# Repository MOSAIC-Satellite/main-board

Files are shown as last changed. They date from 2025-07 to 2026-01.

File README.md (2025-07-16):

# Main Board

This is the repository for MOSAIC's Main Board.

For detailed information on the Main Board, check out its core documentation [here](https://www.mosaicsat.org/core_documentation/hardware/main_board/).

To get your own MOSAIC Main Board, visit the MOSAIC fabrication guide [here](https://www.mosaicsat.org/getting_mosaic/).

## Current Features

*Newest board version: 1.0*

| **Feature** |
| :----------- |
| Swappable Processor Slot |
| 2x Expandable Memory Slots |
| 2x Function Board Slots |
| USB/Battery Voltage Regulator |
| Qwiic Voltage Regulator |
| Built-in Resettable PTC Fuse |
| 2-Pin JST Connector |
| Single Cell LiPo Charge Circuit |
| USB Type C Connector |
| 2x Qwiic Connectors |
| SWD 2x5 Header |
| Multiplexer for UART1  |
| Boot and Reset Buttons |
| 3x I/O switches |

## Planned Changes

The following are the current plans for changes to MOSAIC's Main Board. 

- Remove one of the expandable memory slots and replace it with a permanent SD card slot. This means that those interested only in SD cards for memory storage don't need a separate PCB to add to the board. 

## Change Log

You can find the change log for the Main Board on MOSAIC's website [here](https://www.mosaicsat.org/core_documentation/hardware/main_board/change_log/).

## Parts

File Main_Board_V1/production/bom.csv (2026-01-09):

Designator | Footprint | Quantity | Value | LCSC Part #
C1, C4, C5 | 0603 | 3 | 4.7uF | C1705
C2, C7 | 0805 | 2 | 10uF | C318695
C3 | 0805 | 1 | 0.1uF | C20617880
C6, C8 | 0603 | 2 | 1.0uF | C1592
D1, D2, D3 | LED-0603 | 3 | LED RED CLEAR SMD | C125099
D4 | SMA-DIODE | 1 | DIODE SCHOTTKY 40V 3A SMA | C85098
D5 | LED-0603 | 1 | LED YELLOW CLEAR CHIP SMD | C125095
D6 | SOD-323 | 1 | SOD-323, 3.3V, 0.3W | C550557
F1 | 1210 | 1 | PTC RESET FUSE 6V 2A 1210 | C135353
J1, J3 | M.2-CONNECTOR-E-FUNCTION-STANDARD | 2 | CONN E | C2977809
J10 | JST04_1MM_RA | 1 | Right Angle Qwiic Connector | C7527619
J11 | JST04_1MM_VERT | 1 | Vertical Qwiic Connector | C160390
J12, J13 | M.2-CONNECTOR-E-Memory | 2 | CONN E | C2977809
J2 | M.2-CONNECTOR-E | 1 | CONN E | C2977809
J5 | USB TYPE C RA SMT 16PIN 10155435-00011LF_AMP | 1 | USB TYPE C R/A SMT 16PIN | C5409177
J9 | JST-2-SMD | 1 | CONN_JST_BATT | C47647
Q1 | SOT23-3 | 1 | MOSFET P-CH 30V 3.1A SOT23-3 | C144996
R1 | 0603 | 1 | 19.6k | C22898
R10, R2 | 0603 | 2 | 10k | C840630
R11 | 0603 | 1 | 4.7k | C4293273
R12 | 0603 | 1 | 2.0k | C2076433
R13, R14, R5, R6 | 0603 | 4 | 100k | C237115
R15, R16, R3 | 0603 | 3 | 2.2k | C163872
R4, R7 | 0603 | 2 | 1k | C2484712
R8, R9 | 0603 | 2 | 5.1k | C14677
S1, S2, S3 | SW-SMD_SSSS810701 | 3 | switch | C97433
S4, S5 | TACTILE_SWITCH_SMD_5.2MM | 2 | SMD Switch 5.2mm | C10852
U1 | TDFN-14-1EP_3x3mm_P0.4mm_EP1.78x2.35mm | 1 | IC SWITCH SP3T X 2 750mOhm TDFN-14(3x3) | C1522710
U2 | SOT-23-6 | 1 | TVS DIODE 3.3VWM 6VC SOT26 | C531179
U3 | SOT23-5 | 1 | MCP73831 IC BATT CNTL | C424093
U4 | UDFN-8 | 1 | IC REG LINEAR 3.3V 1A 8UDFN | C151007
U5 | SOT25 | 1 | XC6503D331MR-500mA-3.3V | C2891277

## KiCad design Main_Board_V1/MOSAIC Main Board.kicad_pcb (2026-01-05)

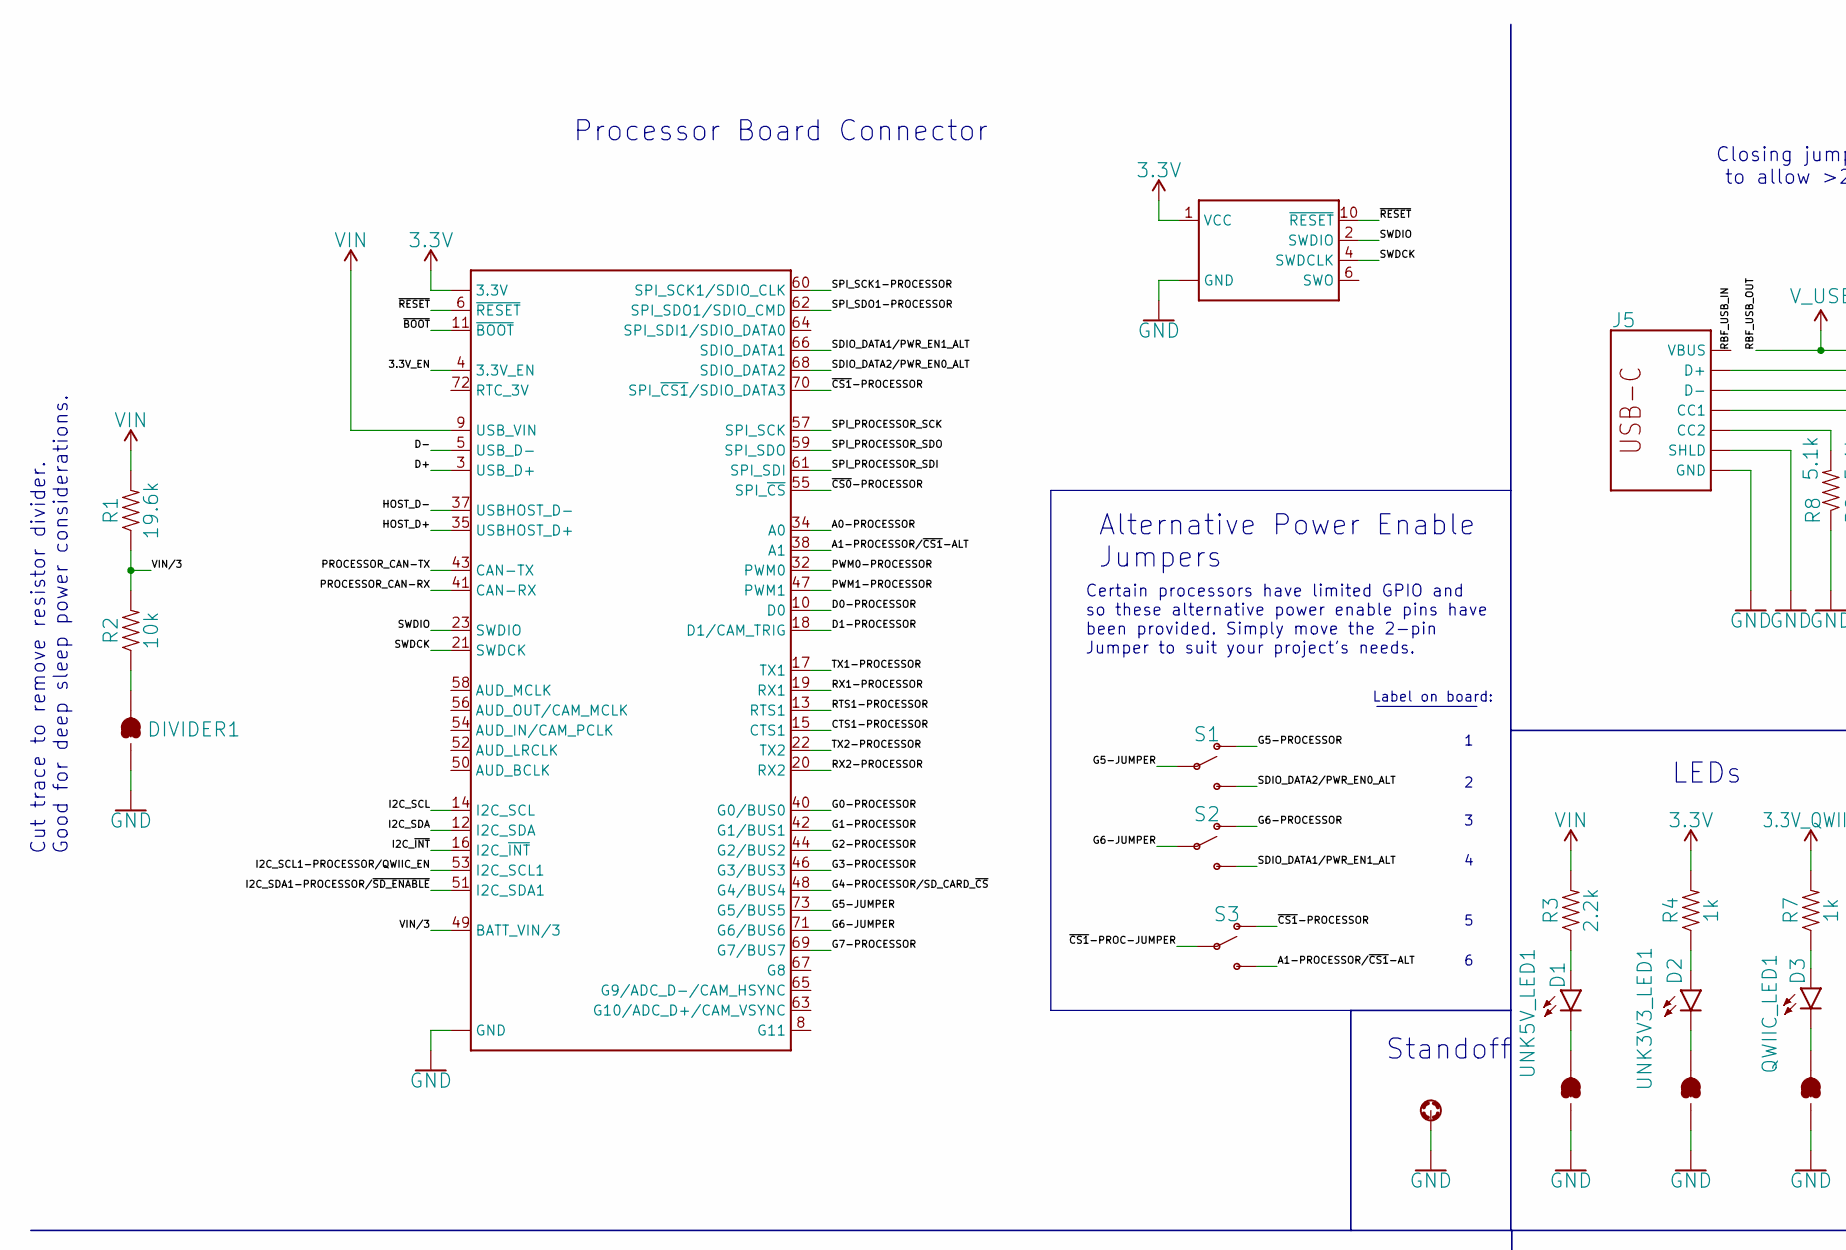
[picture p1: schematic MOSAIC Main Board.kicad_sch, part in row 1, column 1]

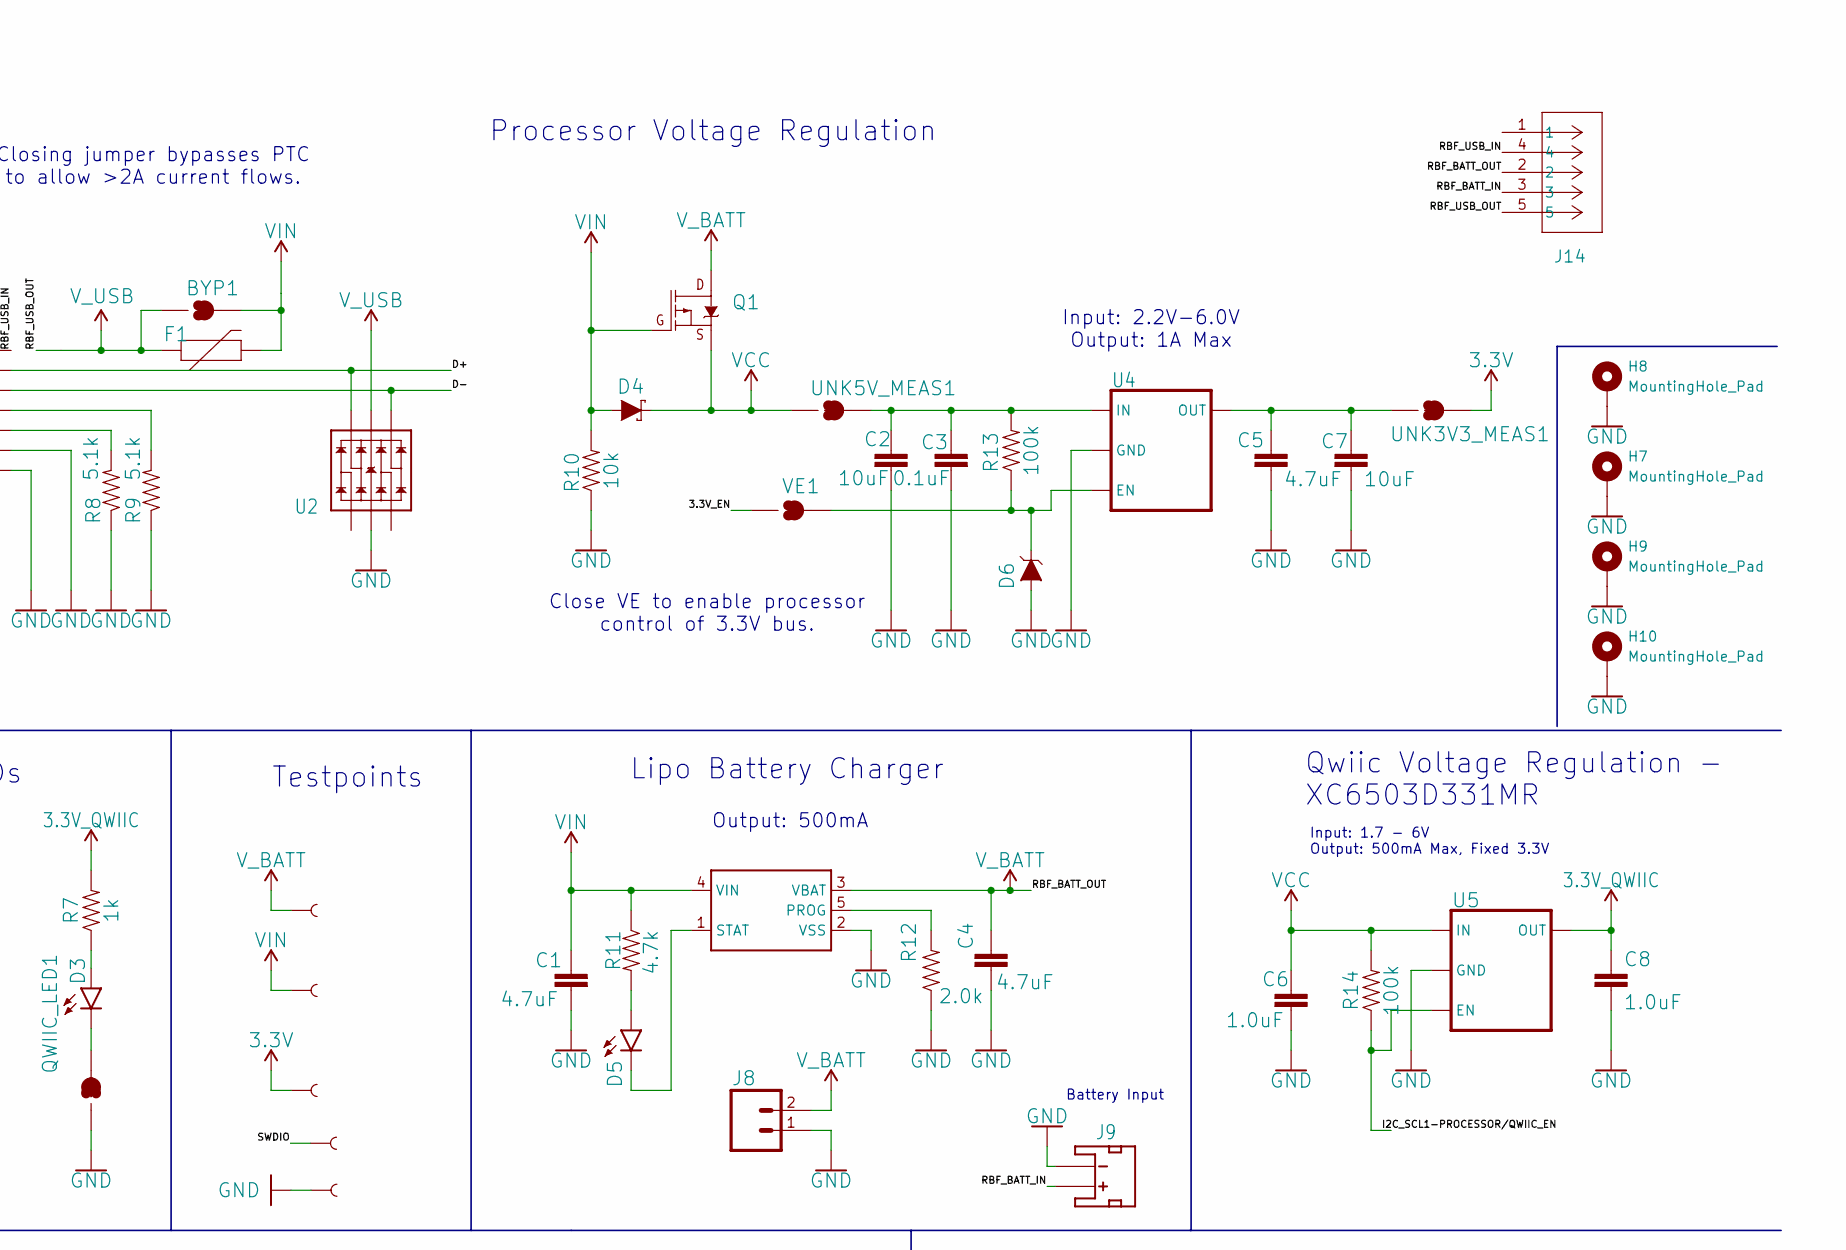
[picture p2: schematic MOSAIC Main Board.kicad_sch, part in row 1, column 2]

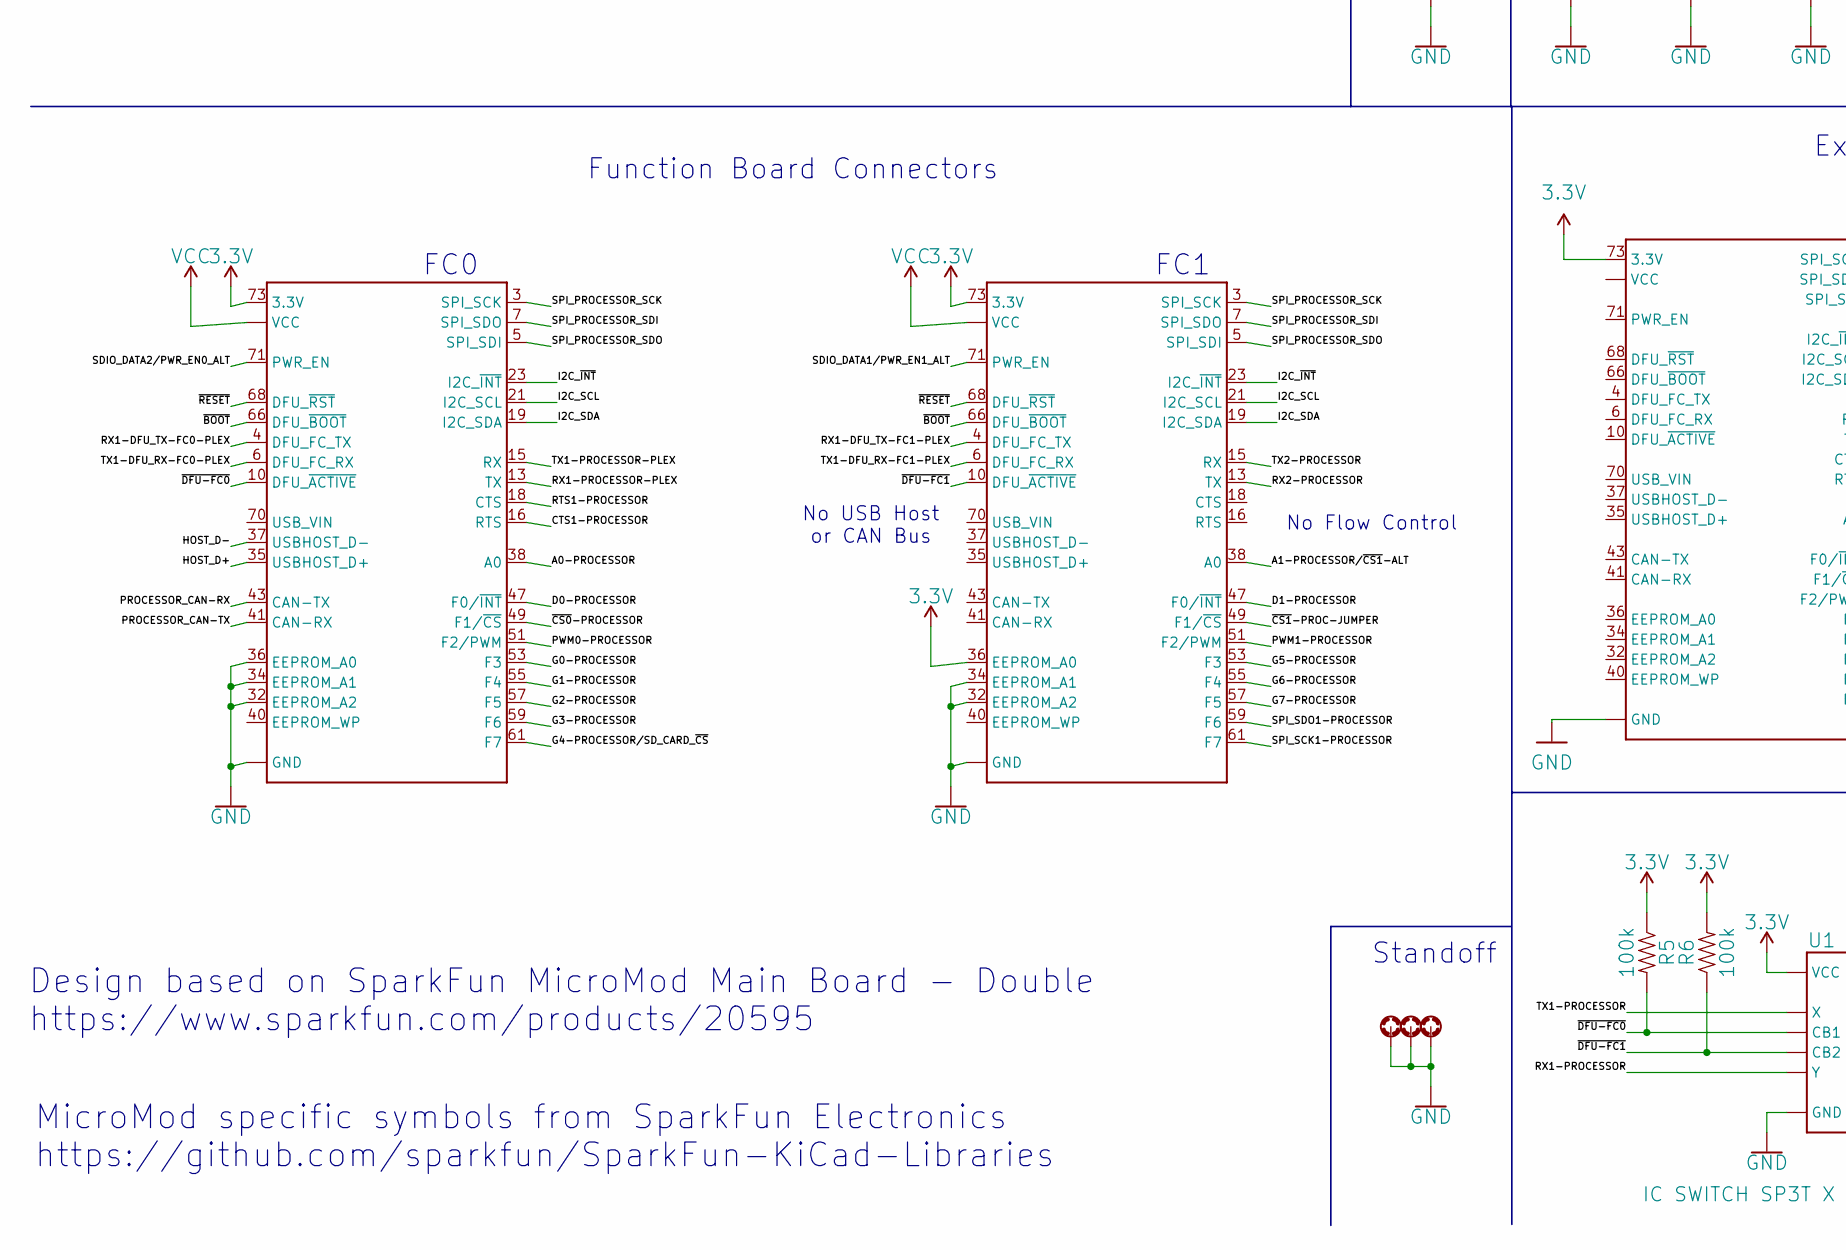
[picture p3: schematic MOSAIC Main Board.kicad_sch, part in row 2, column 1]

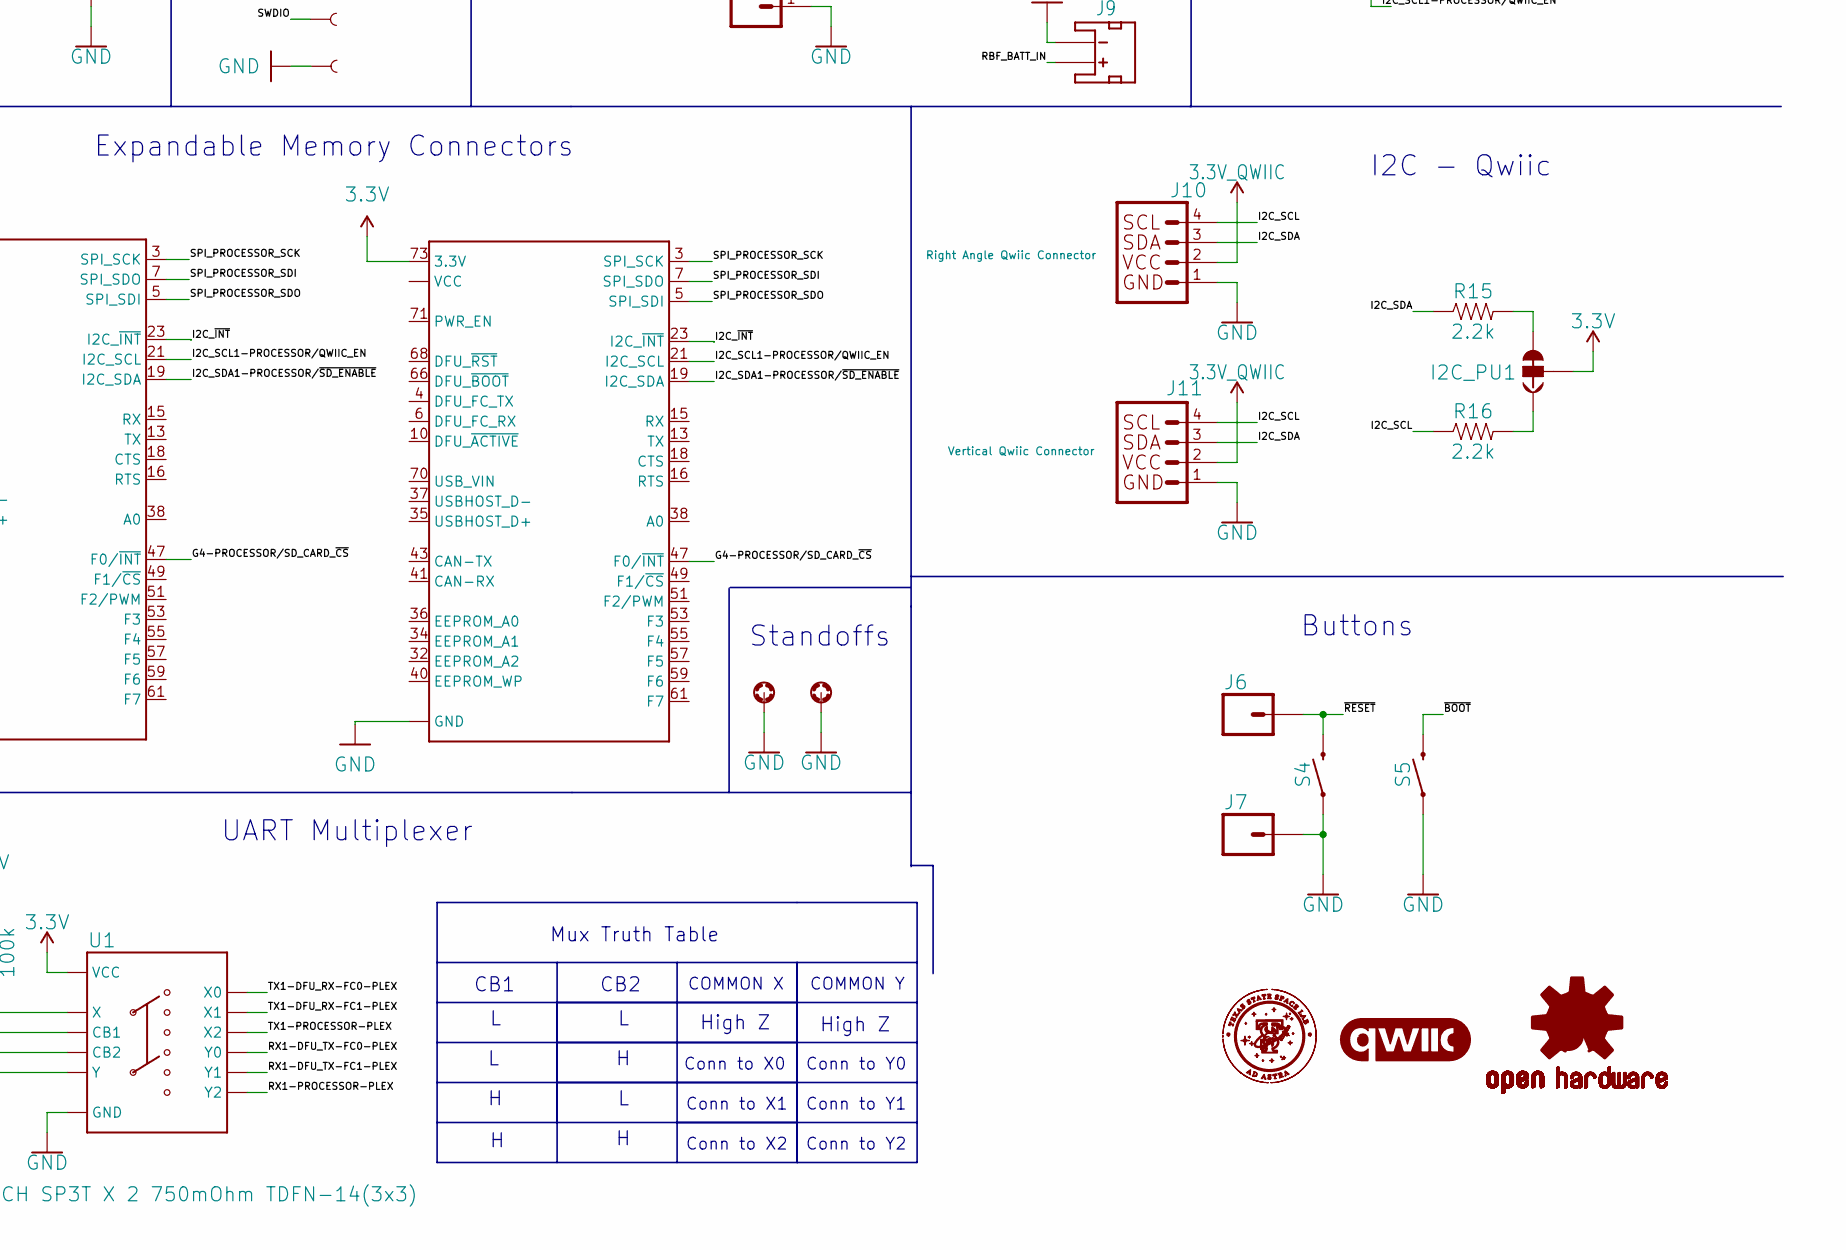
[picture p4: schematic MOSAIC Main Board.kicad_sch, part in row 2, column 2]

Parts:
3.3V1: PAD.03X.05
BYP1: SMT-JUMPER_2_NO_SILK
C1, C4, C5: 4.7uF; 0603; JLCPCB Part # C1705
C2, C7: 10uF; 0805; JLCPCB Part # C318695
C3: 0.1uF; 0805; JLCPCB Part # C20617880
C6, C8: 1.0uF; 0603; JLCPCB Part # C1592
D1, D2, D3: LED RED CLEAR SMD; LED-0603; JLCPCB Part # C125099
D4: DIODE SCHOTTKY 40V 3A SMA; SMA-DIODE; JLCPCB Part # C85098
D5: LED YELLOW CLEAR CHIP SMD; LED-0603; JLCPCB Part # C125095
D6: SOD-323, 3.3V, 0.3W; SOD-323; JLCPCB Part # C550557
DIVIDER1: SMT-JUMPER_2_NC_TRACE_SILK
F1: PTC RESET FUSE 6V 2A 1210; 1210; JLCPCB Part # C135353
GND1: PAD.03X.05
H1, H2, H3, H4, H5, H6: STAND-OFF-REFLOW-M2.5_2.5MM_TALL; STAND-OFF-REFLOW-M2.5
H7, H8: MountingHole_Pad; MountingHole_3.2mm_M3_Pad
H9, H10: MountingHole_Pad; MountingHole_3.2mm_Pad_Oval
I2C_PU1: SMT-JUMPER_3_2-NC_TRACE_SILK
J1, J3: CONN E; M.2-CONNECTOR-E-FUNCTION-STANDARD; JLCPCB Part # C2977809
J2: CONN E; M.2-CONNECTOR-E; JLCPCB Part # C2977809
J4: CONN HEADER VERT 10POS 1.27MM; 2X5-PTH-1.27MM
J5: USB TYPE C R/A SMT 16PIN; USB TYPE C RA SMT 16PIN 10155435-00011LF_AMP; JLCPCB Part # C5409177
J6, J7: 1X01_NO_SILK
J8: 1X02_NO_SILK
J9: CONN_JST_BATT; JST-2-SMD; JLCPCB Part # C47647
J10: Right Angle Qwiic Connector; JST04_1MM_RA; JLCPCB Part # C7527619
J11: Vertical Qwiic Connector; JST04_1MM_VERT; JLCPCB Part # C160390
J12, J13: CONN E; M.2-CONNECTOR-E-Memory; JLCPCB Part # C2977809
J14: 35RAPC4BH3 CONN 3.5MM; CONN_35RAPC4BH3_SWC
LOGO1: QWIIC_LOGO_8MM; QWIIC_8MM
LOGO2: OSHW-LOGOL; OSHW-LOGO-L
Q1: MOSFET P-CH 30V 3.1A SOT23-3; SOT23-3; JLCPCB Part # C144996
QWIIC_LED1: SMT-JUMPER_2_NC_TRACE_SILK
R1: 19.6k; 0603; JLCPCB Part # C22898
R2, R10: 10k; 0603; JLCPCB Part # C840630
R3, R15, R16: 2.2k; 0603; JLCPCB Part # C163872
R4, R7: 1k; 0603; JLCPCB Part # C2484712
R5, R6, R13, R14: 100k; 0603; JLCPCB Part # C237115
R8, R9: 5.1k; 0603; JLCPCB Part # C14677
R11: 4.7k; 0603; JLCPCB Part # C4293273
R12: 2.0k; 0603; JLCPCB Part # C2076433
S1, S2, S3: switch; SW-SMD_SSSS810701; JLCPCB Part # C97433
S4, S5: SMD Switch 5.2mm; TACTILE_SWITCH_SMD_5.2MM; JLCPCB Part # C10852
SWDIO1: PAD.03X.05
U1: IC SWITCH SP3T X 2 750mOhm TDFN-14(3x3); TDFN-14-1EP_3x3mm_P0.4mm_EP1.78x2.35mm; JLCPCB Part # C1522710
U2: TVS DIODE 3.3VWM 6VC SOT26; SOT-23-6; JLCPCB Part # C531179
U3: MCP73831 IC BATT CNTL; SOT23-5; JLCPCB Part # C424093
U4: IC REG LINEAR 3.3V 1A 8UDFN; UDFN-8; JLCPCB Part # C151007
U5: XC6503D331MR-500mA-3.3V; SOT25; JLCPCB Part # C2891277
UNK3V3_LED1, UNK5V_LED1: SMT-JUMPER_2_NC_TRACE_SILK
UNK3V3_MEAS1, UNK5V_MEAS1: COMBO-JUMPER_2_NC_TRACE
VE1: SMT-JUMPER_2_NO_SILK
VIN1: PAD.03X.05
V_BATT1: PAD.03X.05

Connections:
3.3V: 3.3V1.1, I2C_PU1.2, J1.73 (3.3V), J2.2 (3.3V), J2.74 (3.3V), J3.36 (EEPROM_A0), J3.73 (3.3V), J4.1 (VCC), J12.73 (3.3V), J13.73 (3.3V), R4.2, R5.1, R6.2, U1.1 (VCC), UNK3V3_MEAS1.2, UNK3V3_MEAS1.4 (2)
3.3V_QWIIC: C8.1, J10.2, J11.2, R7.2, U5.5 (OUT)
/3.3V_EN: J2.4 (3.3V_EN), VE1.1
/A0-PROCESSOR: J1.38 (A0), J2.34 (A0)
/CTS1-PROCESSOR: J1.16 (RTS), J2.15 (CTS1)
/D0-PROCESSOR: J1.47 (F0/~INT), J2.10 (D0)
/D1-PROCESSOR: J2.18 (D1/CAM_TRIG), J3.47 (F0/~INT)
/D+: J2.3 (USB_D+), J5.A6 (D+), J5.B6 (D+), U2.6 (IO4)
/D-: J2.5 (USB_D-), J5.A7 (D-), J5.B7 (D-), U2.4 (IO3)
/G0-PROCESSOR: J1.53 (F3), J2.40 (G0/BUS0)
/G1-PROCESSOR: J1.55 (F4), J2.42 (G1/BUS1)
/G2-PROCESSOR: J1.57 (F5), J2.44 (G2/BUS2)
/G3-PROCESSOR: J1.59 (F6), J2.46 (G3/BUS3)
/G4-PROCESSOR/SD_CARD_~CS: J1.61 (F7), J2.48 (G4/BUS4), J12.47 (F0/~INT), J13.47 (F0/~INT)
/G5-JUMPER: J2.73 (G5/BUS5), S1.2
/G5-PROCESSOR: J3.53 (F3), S1.1 (O)
/G6-JUMPER: J2.71 (G6/BUS6), S2.2
/G6-PROCESSOR: J3.55 (F4), S2.1 (O)
/G7-PROCESSOR: J2.69 (G7/BUS7), J3.57 (F5)
/HOST_D+: J1.35 (USBHOST_D+), J2.35 (USBHOST_D+)
/HOST_D-: J1.37 (USBHOST_D-), J2.37 (USBHOST_D-)
/I2C_SCL: J1.21 (I2C_SCL), J2.14 (I2C_SCL), J3.21 (I2C_SCL), J10.4, J11.4, R16.1
/I2C_SCL1-PROCESSOR/QWIIC_EN: J2.53 (I2C_SCL1), J12.21 (I2C_SCL), J13.21 (I2C_SCL), R14.1, U5.3 (EN)
/I2C_SDA: J1.19 (I2C_SDA), J2.12 (I2C_SDA), J3.19 (I2C_SDA), J10.3, J11.3, R15.1
/I2C_SDA1-PROCESSOR/~SD_ENABLE: J2.51 (I2C_SDA1), J12.19 (I2C_SDA), J13.19 (I2C_SDA)
/I2C_~INT: J1.23 (I2C_~INT), J2.16 (I2C_~INT), J3.23 (I2C_~INT), J12.23 (I2C_~INT), J13.23 (I2C_~INT)
/PROCESSOR_CAN-RX: J1.43 (CAN-TX), J2.41 (CAN-RX)
/PROCESSOR_CAN-TX: J1.41 (CAN-RX), J2.43 (CAN-TX)
/PWM0-PROCESSOR: J1.51 (F2/PWM), J2.32 (PWM0)
/PWM1-PROCESSOR: J2.47 (PWM1), J3.51 (F2/PWM)
/RBF_BATT_IN: J9.2 (+), J14.3
/RBF_USB_IN: J5.VBUS1 (VBUS), J5.VBUS2 (VBUS), J14.4
/RTS1-PROCESSOR: J1.18 (CTS), J2.13 (RTS1)
/RX1-DFU_TX-FC0-PLEX: J1.4 (DFU_FC_TX), U1.9 (Y0)
/RX1-DFU_TX-FC1-PLEX: J3.4 (DFU_FC_TX), U1.11 (Y1)
/RX1-PROCESSOR: J2.19 (RX1), U1.14 (Y)
/RX1-PROCESSOR-PLEX: J1.13 (TX), U1.12 (Y2)
/RX2-PROCESSOR: J2.20 (RX2), J3.13 (TX)
/SDIO_DATA2/PWR_EN0_ALT: J1.71 (PWR_EN), J2.68 (SDIO_DATA2), S1.3 (S)
/SPI_PROCESSOR_SCK: J1.3 (SPI_SCK), J2.57 (SPI_SCK), J3.3 (SPI_SCK), J12.3 (SPI_SCK), J13.3 (SPI_SCK)
/SPI_PROCESSOR_SDI: J1.7 (SPI_SDO), J2.61 (SPI_SDI), J3.7 (SPI_SDO), J12.7 (SPI_SDO), J13.7 (SPI_SDO)
/SPI_PROCESSOR_SDO: J1.5 (SPI_SDI), J2.59 (SPI_SDO), J3.5 (SPI_SDI), J12.5 (SPI_SDI), J13.5 (SPI_SDI)
/SPI_SCK1-PROCESSOR: J2.60 (SPI_SCK1/SDIO_CLK), J3.61 (F7)
/SPI_SDO1-PROCESSOR: J2.62 (SPI_SDO1/SDIO_CMD), J3.59 (F6)
/SWDCK: J2.21 (SWDCK), J4.4 (SWDCLK)
/SWDIO: J2.23 (SWDIO), J4.2 (SWDIO), SWDIO1.1
/TX1-DFU_RX-FC0-PLEX: J1.6 (DFU_FC_RX), U1.7 (X0)
/TX1-DFU_RX-FC1-PLEX: J3.6 (DFU_FC_RX), U1.5 (X1)
/TX1-PROCESSOR: J2.17 (TX1), U1.2 (X)
/TX1-PROCESSOR-PLEX: J1.15 (RX), U1.4 (X2)
/TX2-PROCESSOR: J2.22 (TX2), J3.15 (RX)
/VIN/3: J2.49 (BATT_VIN/3), R1.1, R2.2
/~BOOT: J1.66 (DFU_~BOOT), J2.11 (~BOOT), J3.66 (DFU_~BOOT), S5.3 (2), S5.4 (2)
/~CS0-PROCESSOR: J1.49 (F1/~CS), J2.55 (SPI_~CS)
/~CS1-PROC-JUMPER: J3.49 (F1/~CS), S3.2
/~CS1-PROCESSOR: J2.70 (SPI_~CS1/SDIO_DATA3), S3.1 (O)
/~DFU-FC0: J1.10 (DFU_~ACTIVE), R5.2, U1.6 (CB1)
/~DFU-FC1: J3.10 (DFU_~ACTIVE), R6.1, U1.13 (CB2)
/~RESET: J1.68 (DFU_~RST), J2.6 (~RESET), J3.68 (DFU_~RST), J4.10 (~RESET), J6.1, S4.3 (2), S4.4 (2)
GND: C1.2, C2.2, C3.2, C4.2, C5.2, C6.2, C7.2, C8.2, D6.A, DIVIDER1.1, GND1.1, H1.1, H2.1, H3.1, H4.1, H5.1, H6.1, H7.1, H8.1, H9.1, H10.1, J1.1 (GND), J1.2 (GND), J1.8 (GND), J1.32 (EEPROM_A2), J1.33 (GND), J1.34 (EEPROM_A1), J1.36 (EEPROM_A0), J1.39 (GND), J1.45 (GND), J1.75 (GND), J2.1 (GND), J2.7 (GND), J2.33 (GND), J2.36 (GND), J2.39 (GND), J2.45 (GND), J2.75 (GND), J3.1 (GND), J3.2 (GND), J3.8 (GND), J3.32 (EEPROM_A2), J3.33 (GND), J3.34 (EEPROM_A1), J3.39 (GND), J3.45 (GND), J3.75 (GND), J4.3 (GND), J4.5 (GND), J4.9 (GND), J5.GND, J5.GND2 (GND), J5.SHLD1 (SHLD), J5.SHLD2 (SHLD), J5.SHLD3 (SHLD), J5.SHLD4 (SHLD), J7.1, J8.1, J9.1 (-), J10.1, J11.1, J12.1 (GND), J12.2 (GND), J12.8 (GND), J12.33 (GND), J12.39 (GND), J12.45 (GND), J12.75 (GND), J13.1 (GND), J13.2 (GND), J13.8 (GND), J13.33 (GND), J13.39 (GND), J13.45 (GND), J13.75 (GND), QWIIC_LED1.1, R8.1, R9.1, R10.1, R12.1, S4.1, S4.2 (1), S5.1, S5.2 (1), U1.8 (GND), U2.2 (VSS), U3.2 (VSS), U4.4 (GND), U4.EP (GND), U5.2 (GND), UNK3V3_LED1.1, UNK5V_LED1.1
unnamed: D1.A, R3.1
unnamed: D1.C, UNK5V_LED1.2
unnamed: D2.A, R4.1
unnamed: D2.C, UNK3V3_LED1.2
unnamed: D3.A, R7.1
unnamed: D3.C, QWIIC_LED1.2
unnamed: D5.A, R11.2
unnamed: DIVIDER1.2, R2.1
unnamed: I2C_PU1.1, R16.2
unnamed: I2C_PU1.3, R15.2
unnamed: J5.A5 (CC1), R9.2
unnamed: J5.B5 (CC2), R8.2
unnamed: J12.72 (VCC), J12.74 (VCC)
unnamed: J13.72 (VCC), J13.74 (VCC)
unnamed: R12.2, U3.5 (PROG)
unnamed: D5.C, U3.1 (STAT)
unnamed: D6.C, R13.1, U4.5 (EN), VE1.2
unnamed: C2.1, C3.1, R13.2, U4.8 (IN), UNK5V_MEAS1.2, UNK5V_MEAS1.4 (2)
unnamed: C5.1, C7.1, U4.1 (OUT), UNK3V3_MEAS1.1, UNK3V3_MEAS1.3 (1)
VCC: C6.1, D4.C, J1.72 (VCC), J1.74 (VCC), J3.72 (VCC), J3.74 (VCC), Q1.2 (S), R14.2, U5.1 (IN), UNK5V_MEAS1.1, UNK5V_MEAS1.3 (1)
VIN: BYP1.2, C1.1, D4.A, F1.2, J2.9 (USB_VIN), Q1.1 (G), R1.2, R3.2, R10.2, R11.1, U3.4 (VIN), VIN1.1
V_BATT: C4.1, J8.2, J14.2, Q1.3 (D), U3.3 (VBAT), V_BATT1.1
V_USB: BYP1.1, F1.1, J14.5, U2.5 (VCC)

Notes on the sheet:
Label on board:
FC1
Function Board Connectors
Conn to X2
Design based on SparkFun MicroMod Main Board - Double https://www.sparkfun.com/products/20595
Battery Input
I2C - Qwiic
Standoff
Mux Truth Table
Processor Voltage Regulation
Conn to Y1
High Z
Conn to Y2
Conn to Y0
Processor Board Connector
No Flow Control
MicroMod specific symbols from SparkFun Electronics https://github.com/sparkfun/SparkFun-KiCad-Libraries
Testpoints
Input: 1.7 - 6V Output: 500mA Max, Fixed 3.3V
Lipo Battery Charger
FC0
Output: 500mA
Cut trace to remove resistor divider. Good for deep sleep power considerations.
Close VE to enable processor control of 3.3V bus.
Buttons
Expandable Memory Connectors
Alternative Power Enable Jumpers
CB2
UART Multiplexer
COMMON Y
Certain processors have limited GPIO and so these alternative power enable pins have been provided. Simply move the 2-pin Jumper to suit your project's needs.
Input: 2.2V-6.0V Output: 1A Max
Conn to X0
LEDs
Closing jumper bypasses PTC to allow >2A current flows.
Conn to X1
No USB Host or CAN Bus
CB1
COMMON X
Standoffs

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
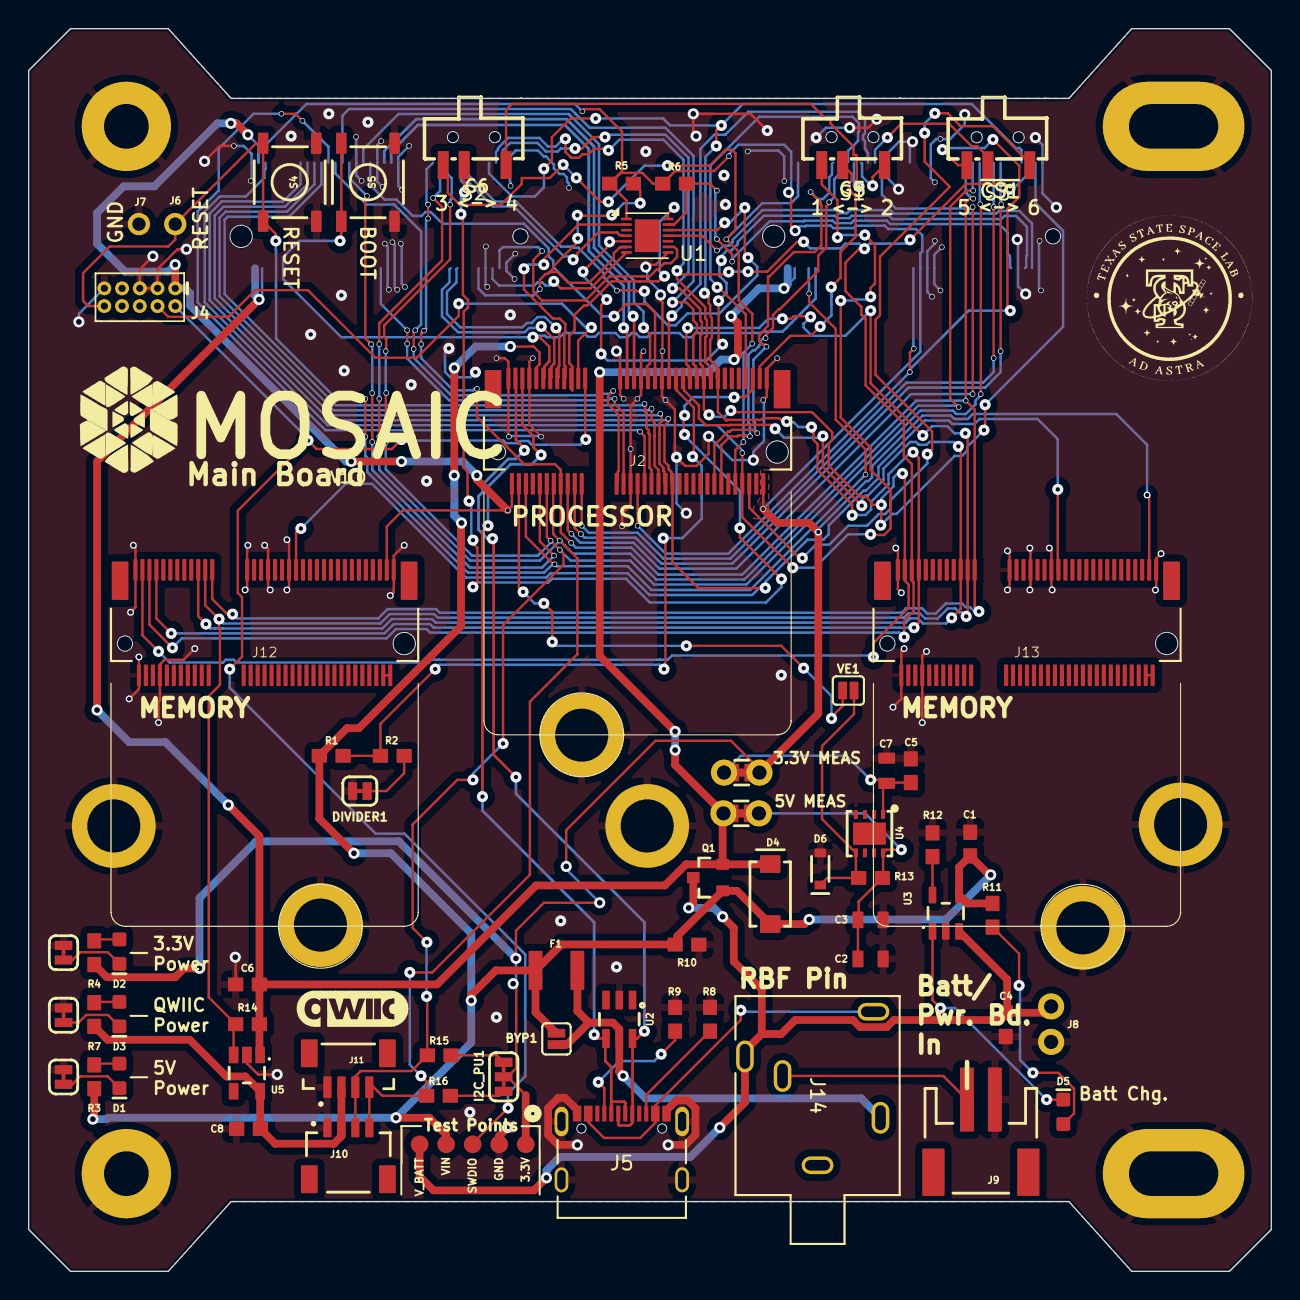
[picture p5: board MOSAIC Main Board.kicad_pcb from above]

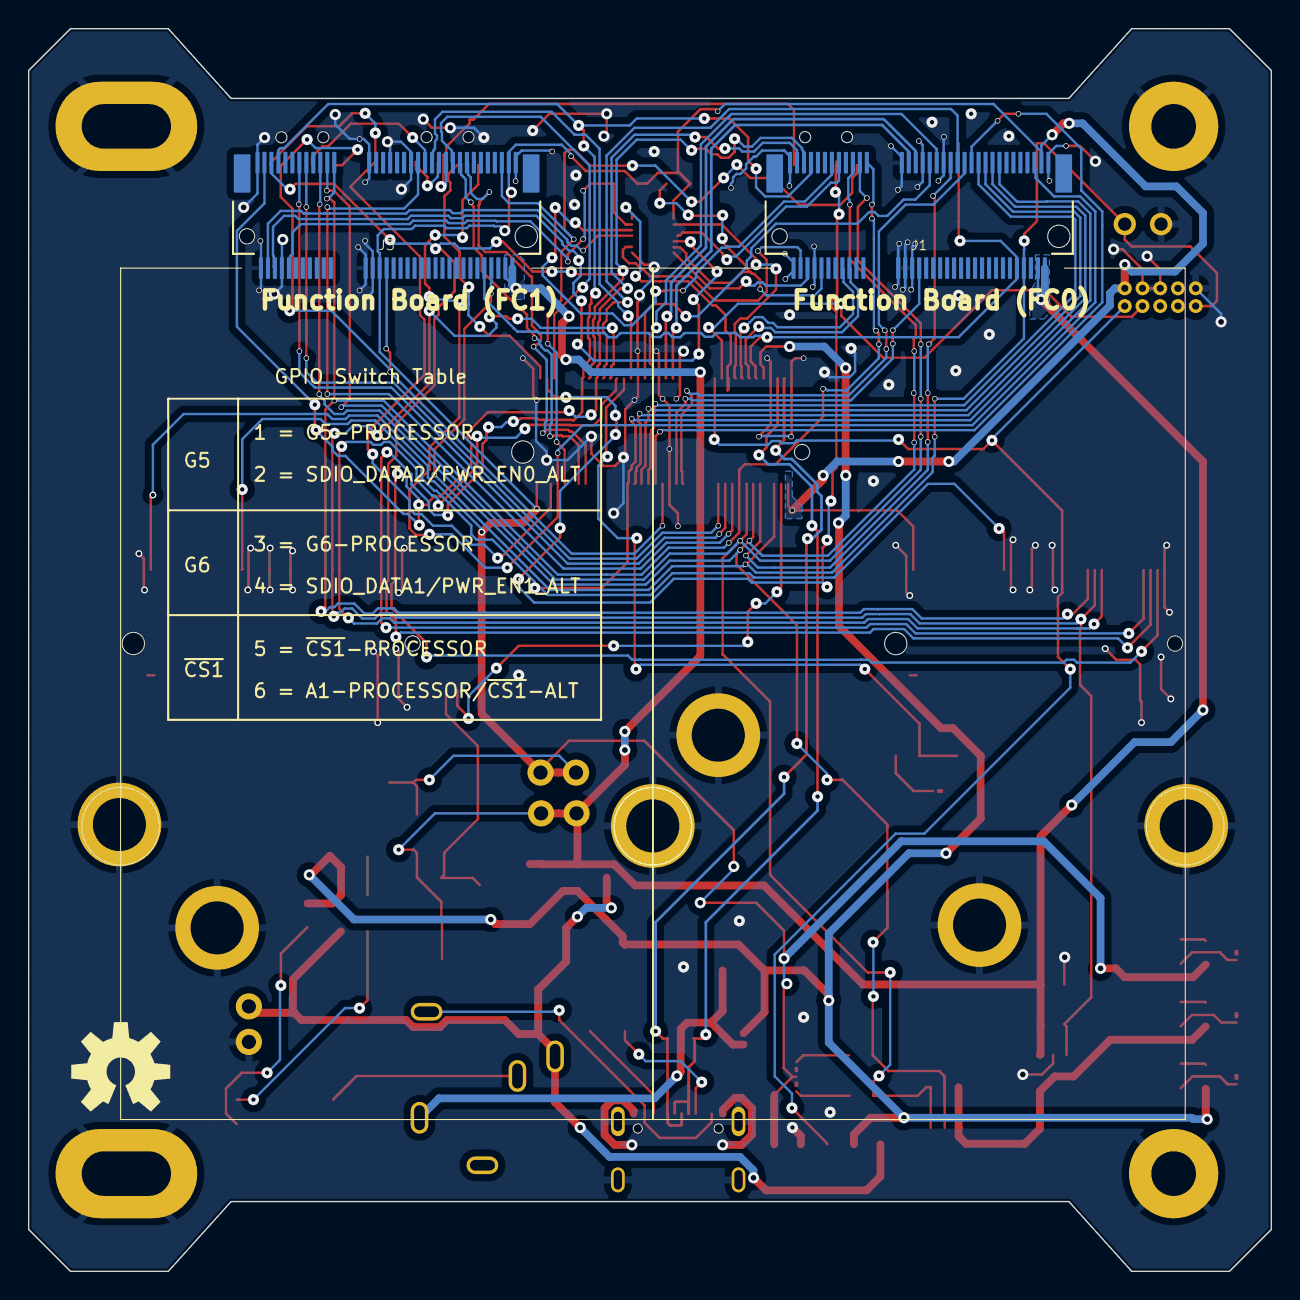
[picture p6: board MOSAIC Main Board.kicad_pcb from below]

Board: 2 copper layers, 89.0 x 89.0 mm, 82 parts (6 on the bottom side), 85 nets.

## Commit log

2024-07-10 Initial Adding of Files
    [MOSAIC Main Board.kicad_pcb, MOSAIC Main Board.kicad_sch]
2024-07-10 Update MOSAIC Main Board.kicad_pcb
    [MOSAIC Main Board.kicad_pcb]
2025-04-16 Updated files from KiCAD 7.0 to 9.0
    [MOSAIC Main Board.kicad_pcb]
2025-04-16 Created board outline drawing
    Created the outline drawing for the new, standardized, board outline.
    [MOSAIC Main Board.kicad_pcb]
2025-04-16 Updated schematic from KiCAD 7.0 to 9.0
    [MOSAIC Main Board.kicad_sch]
2025-04-16 Changed schematic rev number
    [MOSAIC Main Board.kicad_sch]
2025-04-16 Revert back to fix bug
    [MOSAIC Main Board.kicad_pcb]
2025-04-16 Added new board cutout and m3 mount holes
    [MOSAIC Main Board.kicad_pcb, MOSAIC Main Board.kicad_sch]
2025-04-16 Made new board cutout and added m3 mount holes.
    [MOSAIC Main Board.kicad_pcb]
2025-04-16 Moved stuff around
    [MOSAIC Main Board.kicad_pcb]
2025-04-29 Updated component sourcing
    For C2 and C3
    [MOSAIC Main Board.kicad_sch]
2025-04-29 Updated source for R2
    [MOSAIC Main Board.kicad_sch]
2025-04-29 Updated source for R12
    [MOSAIC Main Board.kicad_sch]
2025-04-29 Updated source for J9
    [MOSAIC Main Board.kicad_sch]
2025-04-29 Updated source J14
    [MOSAIC Main Board.kicad_sch]
2025-04-29 Updated source for U2
    [MOSAIC Main Board.kicad_sch]
2025-04-30 Updated footprint for S1
    [MOSAIC Main Board.kicad_sch]
2025-04-30 Updated measurements for board outline
    [MOSAIC Main Board.kicad_pcb]
2025-04-30 Added ground plane to new board outline
    [MOSAIC Main Board.kicad_pcb]
2025-04-30 Deleted old tracks and started organizing surface components
    [MOSAIC Main Board.kicad_pcb]
2025-05-05 Wired/Placed processor/x2 module connectors
    [MOSAIC Main Board.kicad_pcb]
2025-05-28 Lots of placements and routing
    [MOSAIC Main Board.kicad_pcb]
2025-05-29 More placement and routing work
    [MOSAIC Main Board.kicad_pcb]
2025-05-29 More placement and routing
    [MOSAIC Main Board.kicad_pcb]
2025-05-30 Placement and routing
    [MOSAIC Main Board.kicad_pcb, MOSAIC Main Board.kicad_sch]
2025-05-30 Small correction
    [MOSAIC Main Board.kicad_pcb]
2025-06-13 Changed user.1 to user.5
    [MOSAIC Main Board.kicad_pcb]
2025-06-13 Updating JLCPCB sources
    [MOSAIC Main Board.kicad_pcb, MOSAIC Main Board.kicad_sch]
2025-06-13 updating JLCPCB comp sources
    [MOSAIC Main Board.kicad_sch]
2025-06-13 add jlcpcb comp sources
    [MOSAIC Main Board.kicad_sch]
2025-06-13 added jlcpcb comp sources
    [MOSAIC Main Board.kicad_sch]
2025-06-13 finished comp sourcing
    [MOSAIC Main Board.kicad_sch]
2025-06-14 Finish comp placement
    [MOSAIC Main Board.kicad_pcb, MOSAIC Main Board.kicad_sch]
2025-06-14 started JLCPCB setup
    [MOSAIC Main Board.kicad_pcb, MOSAIC Main Board.kicad_sch]
2025-06-14 Finished JLCPCB setup
    [MOSAIC Main Board.kicad_pcb, MOSAIC Main Board.kicad_sch]
2025-06-16 added bom
    Added bom for assembly after JLCPCB assembly.
    [MOSAIC Main Board.kicad_pcb, MOSAIC Main Board.kicad_sch]
2025-06-23 small edits
    [MOSAIC Main Board.kicad_pcb]
2025-06-23 fixed jlcpcb comp placement
    [MOSAIC Main Board.kicad_pcb, MOSAIC Main Board.kicad_sch]
2025-06-24 minor changes to text sizing
    [MOSAIC Main Board.kicad_pcb, MOSAIC Main Board.kicad_sch]
2025-06-24 board text adjustments
    [MOSAIC Main Board.kicad_pcb, MOSAIC Main Board.kicad_sch]
2025-06-26 Started adding 3d models
    [MOSAIC Main Board.kicad_pcb]
2025-07-12 fix batt input
    [MOSAIC Main Board.kicad_sch]
2025-07-16 added switch table to back
    [MOSAIC Main Board.kicad_pcb]
2025-07-17 new production folder
    [MOSAIC Main Board.kicad_pcb]
2025-07-21 Update MOSAIC Main Board.kicad_sch
    [MOSAIC Main Board.kicad_sch]
2025-07-29 added new html BOM
    [MOSAIC Main Board.kicad_pcb]
2026-01-04 labeled the fc board slots
    [MOSAIC Main Board.kicad_pcb]
2026-01-04 added more labels
    [MOSAIC Main Board.kicad_pcb]
2026-01-05 replaced out of stock switches
    [MOSAIC Main Board.kicad_pcb, MOSAIC Main Board.kicad_sch]
2026-01-09 Made new fab files
    Made new fabrication files for JLCPCB production that include the most recent changes to the board.
    [bom.csv, positions.csv]

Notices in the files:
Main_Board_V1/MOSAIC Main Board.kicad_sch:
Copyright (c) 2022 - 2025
